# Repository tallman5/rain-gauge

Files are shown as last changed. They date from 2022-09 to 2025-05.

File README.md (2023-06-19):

## Links
||Desc|Link|
|---|---|---|
|**Documentation**|Published docs and Discuss|[https://www.mcgurkin.net/posts/rain-gauge](https://www.mcgurkin.net/posts/rain-gauge)|
|**YouTube**|Short video of tipper working|[https://youtu.be/XX34wHzLibE](https://youtu.be/XX34wHzLibE)|
|**Rain History**|Sensor output charts|[https://www.mcgurkin.net/apps/rain](https://www.mcgurkin.net/apps/rain)|
|**BOM**|List of parts required for full build|[https://github.com/tallman5/rain-gauge/blob/main/rain-gauge-bom.md](https://github.com/tallman5/rain-gauge/blob/main/rain-gauge-bom.md)|
|**Fusion Model**|The STLs in GitHub are the "production" version. The Fusion model may have changes which have not been tested.|[https://a360.co/3bst4iC](https://a360.co/3bst4iC)|

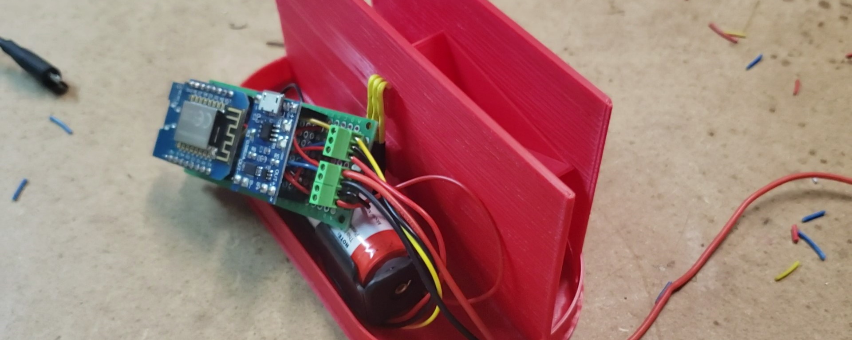
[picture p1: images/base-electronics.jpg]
Rain Gauge Electronics


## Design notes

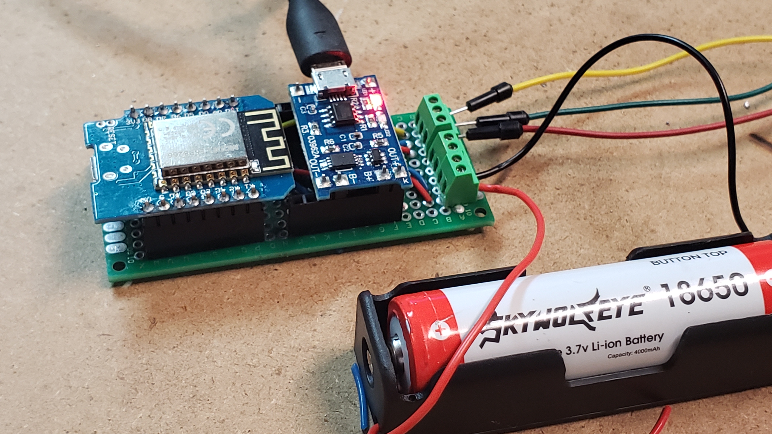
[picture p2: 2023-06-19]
images/rain-gauge-electronics.jpg

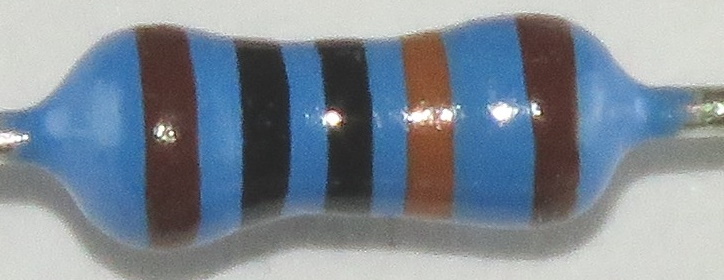
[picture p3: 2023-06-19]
images/100k-resistor.jpg

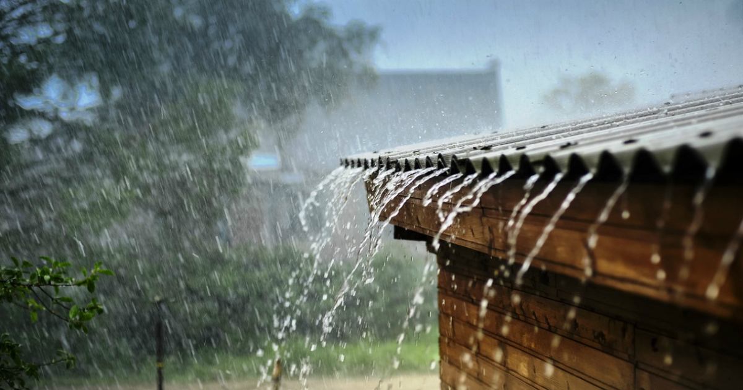
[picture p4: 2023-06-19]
images/rain-roof.jpg

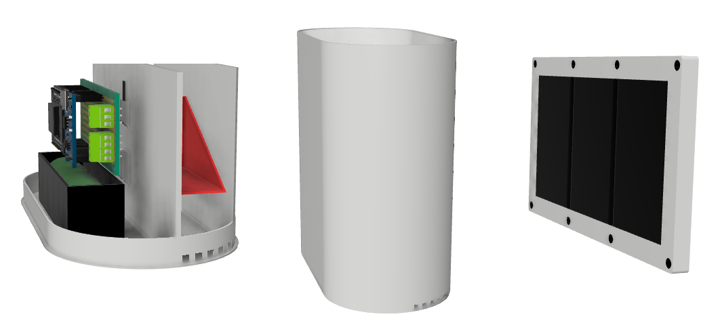
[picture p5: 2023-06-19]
images/rain-gauge.png

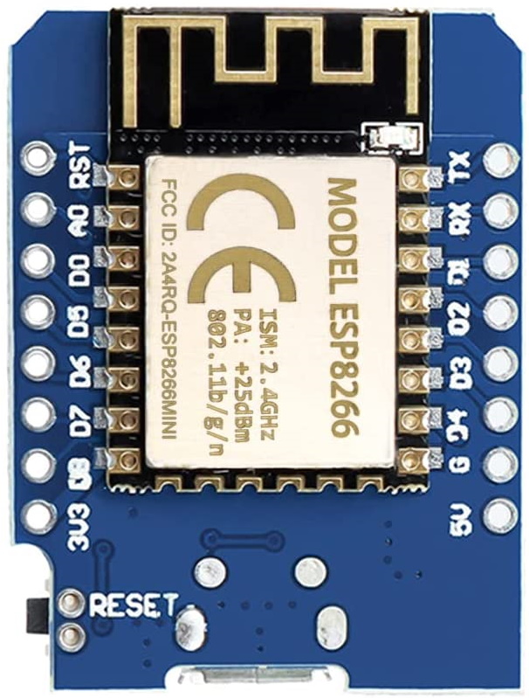
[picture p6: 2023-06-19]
images/ESP8266-top.jpg

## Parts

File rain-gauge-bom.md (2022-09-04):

# Rain Gauge BOM
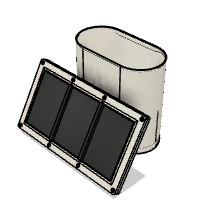
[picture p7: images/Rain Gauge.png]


As an Amazon Associate I earn from qualifying purchases. The products in the links below will not cost you any more than normally. However, using these links helps support this and other projects. Thank you!

|Image|Number|Quantity|Description|
|-|-|-|-|
||18650 Battery|1|https://amzn.to/3APuPyO|
||18650 Holder|1|https://amzn.to/3TGcAo7|
||2.54 Header 1 Pin Male|2|https://amzn.to/3KK6nDy|
||2.54 Header 2 Pin Male|2|https://amzn.to/3KK6nDy|
||2.54 Header 8 Pin Female|4|https://amzn.to/3CS7b7p|
||2.54 Header 8 Pin Male|2|https://amzn.to/3CS7b7p|
||5v Solar Panel|3|https://amzn.to/3wUnVHu|
||Hall Sensor AH3364Q|1|https://amzn.to/3qakI2M|
||Schottky Diode 1N5817|3|https://amzn.to/3CWOjnV|
||ESP8266 12F|1|https://amzn.to/3CS7b7p|
||KF128-2.54-2P|2|https://amzn.to/3KK6nDy|
||KF128-2.54-3P|1|https://amzn.to/3KK6nDy|
||M3x5x4 Threaded Insert|8|https://amzn.to/3AGMAjQ|
||M3x6 SHCS|8|https://amzn.to/3QjYiGJ|
||M6x3 Magnet|1|https://amzn.to/3RhCIUT|
||panel-holder-bottom|1|3D Printed Part|
||panel-holder-top|1|3D Printed Part|
||Prototype Board 24x10|1|https://amzn.to/3KK6nDy|
||rain-gauge-base|1|3D Printed Part|
||rain-gauge-cup|1|3D Printed Part|
||rain-gauge-top|1|3D Printed Part|
||Resistor - 100K|2|https://amzn.to/3AP3Za0|
||TP4056|1|https://amzn.to/3e9tIST|

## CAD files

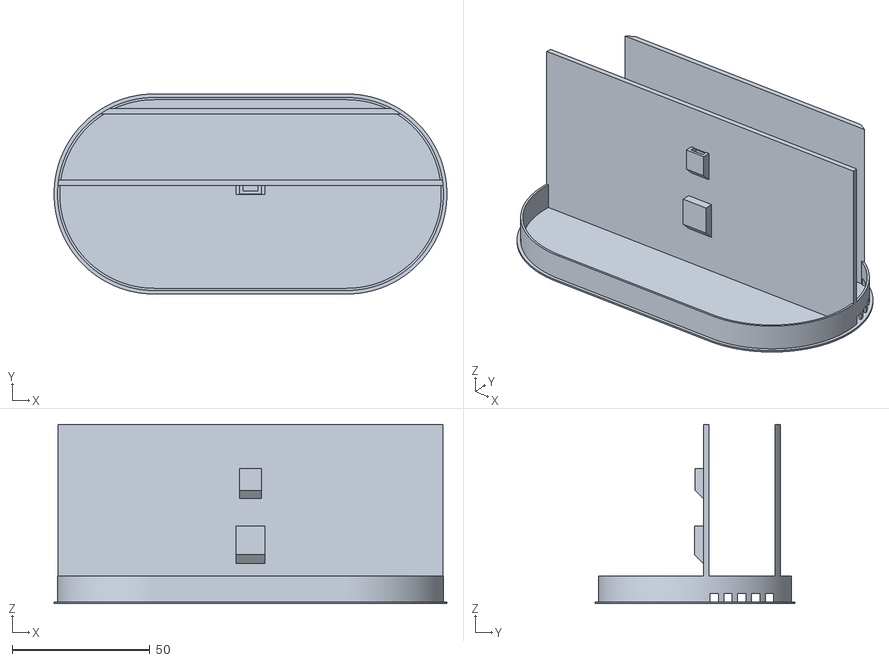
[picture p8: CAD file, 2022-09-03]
stl/rain-gauge-base.stl
142.6 x 72.6 x 65.0

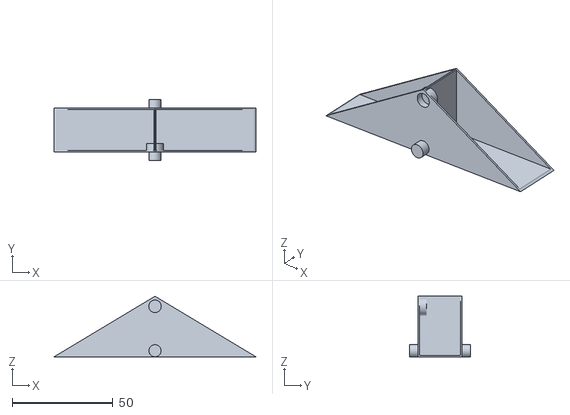
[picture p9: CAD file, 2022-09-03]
stl/rain-gauge-cup.stl
100.0 x 30.0 x 30.0

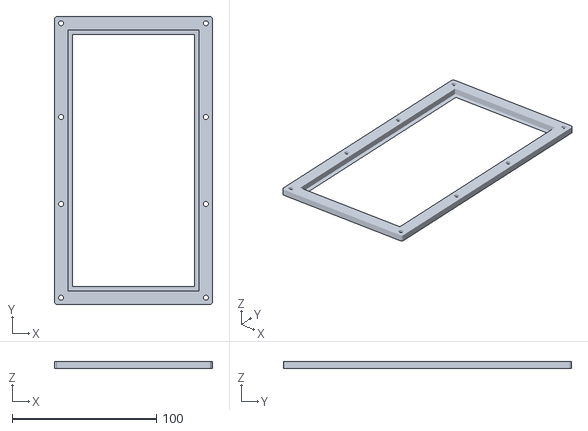
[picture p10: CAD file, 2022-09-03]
stl/panel-holder-top.stl
109.8 x 199.8 x 4.60

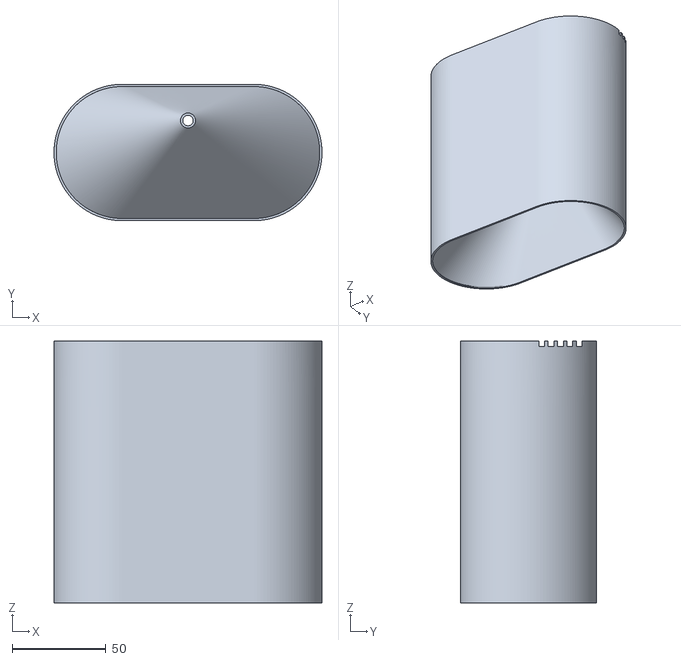
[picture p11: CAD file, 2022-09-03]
stl/rain-gauge-top.stl
142.6 x 72.6 x 139.4

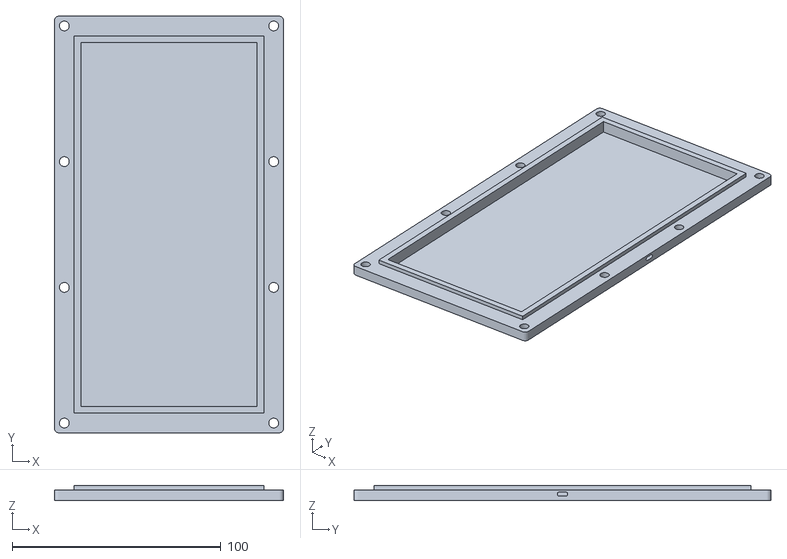
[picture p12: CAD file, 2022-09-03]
stl/panel-holder-bottom.stl
109.8 x 199.8 x 7.00

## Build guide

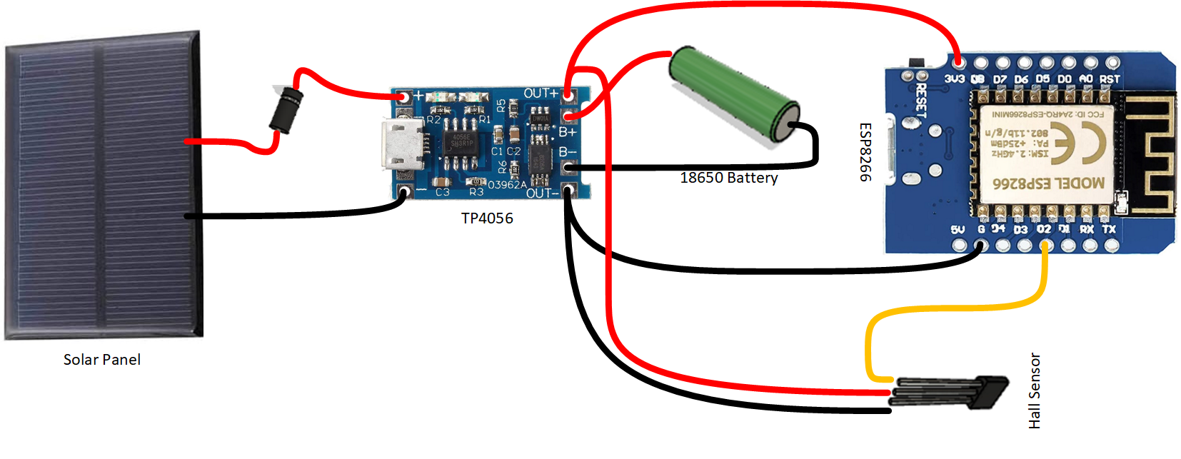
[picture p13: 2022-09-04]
images/rain-gauge-wiring.png

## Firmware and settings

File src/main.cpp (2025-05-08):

#include <ArduinoJson.h>
#include <ESP8266HTTPClient.h>
#include <ESP8266mDNS.h>
#include <ESP8266WiFi.h>
#include <list>
#include <time.h>
#include "secrets.h"

#define INTERRUPT_PIN D2
#define VOLTAGE_PIN A0

const char *hostName = HOST_NAME;
const char *ssid = STASSID;
const char *wifiPassword = STAPSK;
const char *baseApiUrl = BASE_API_URL;
const char *iotName = IOT_NAME;
const char *iotPassword = IOT_PASSWORD;

float voltCalibration = 0.382;
long lastPostTime = 0;
String accessToken;
std::list<long> epochs;
String bulkUploadEndpoint = "/kpis/" + String(hostName);
int counter = 0;

void turnOffWifi()
{
  Serial.print("Disconnecting WiFi..");
  WiFi.mode(WIFI_OFF);
  while (WiFi.status() == WL_CONNECTED)
  {
    Serial.print(".");
    delay(1000);
  }
  Serial.println("done");
}

void turnOnWifi()
{
  Serial.print("Connecting to WiFi.");
  WiFi.hostname(hostName);
  WiFi.mode(WIFI_STA);
  WiFi.begin(ssid, wifiPassword);
  while (WiFi.status() != WL_CONNECTED)
  {
    delay(1000);
    Serial.print(".");
  }
  Serial.println("done");
  Serial.println("IP address: " + WiFi.localIP().toString());
  Serial.println("MAC address: " + WiFi.macAddress());
}

IRAM_ATTR void hallChanged()
{
  const int currentRead = digitalRead(INTERRUPT_PIN);
  if (currentRead == 0)
  {
    long now = time(nullptr);
    epochs.push_back(now);
    digitalWrite(LED_BUILTIN, LOW);
    Serial.println("Hall effect sensor triggered.");
  }
  else
  {
    digitalWrite(LED_BUILTIN, HIGH);
  }
}

int postJsonWithAuth(const String &endpoint, const String &jsonBody)
{
  if (WiFi.status() != WL_CONNECTED || accessToken.isEmpty())
    return -1;

  std::unique_ptr<BearSSL::WiFiClientSecure> client(new BearSSL::WiFiClientSecure);
  client->setInsecure();

  HTTPClient https;
  if (!https.begin(*client, String(baseApiUrl) + endpoint))
  {
    Serial.println("Unable to connect to server for " + endpoint);
    return -1;
  }

  https.addHeader("Content-Type", "application/json");
  https.addHeader("Authorization", "Bearer " + accessToken);

  int httpCode = https.POST(jsonBody);
  Serial.printf("POST to %s response code: %d\n", endpoint.c_str(), httpCode);

  if (httpCode <= 0)
  {
    Serial.printf("Failed to POST to %s, error: %s\n", endpoint.c_str(), https.errorToString(httpCode).c_str());
    String errorPayload = https.getString();
    Serial.println("Error Response: " + errorPayload);
  }

  https.end();
  return httpCode;
}

String createKpiJson(const String &keyName, float keyValue, long epoch)
{
  String json = "{";
  json += "\"keyName\":\"" + keyName + "\",";
  json += "\"keyValue\":" + String(keyValue, 2) + ",";
  json += "\"epoch\":" + String(epoch);
  json += "}";
  return json;
}

void postKpis(bool includeTips)
{
  int sensorValue = analogRead(VOLTAGE_PIN);
  float voltage = ((sensorValue * (3.3 / 1024.0)) * 2) + voltCalibration;
  int battPercent = (voltage - 2.5) * 100 / (4.2 - 2.5);
  long now = time(nullptr);

  String json = "{ \"kpis\": [";
  bool first = true;

  if (includeTips)
  {
    for (auto it = epochs.begin(); it != epochs.end(); ++it)
    {
      if (!first)
        json += ",";
      json += createKpiJson("tip", 1, *it);
      first = false;
    }
  }

  if (!first)
    json += ",";
  json += createKpiJson("volt", voltage, now);
  json += "," + createKpiJson("volt-pin", sensorValue, now);
  json += "," + createKpiJson("batt", battPercent, now);

  json += "] }";

  int httpCode = postJsonWithAuth(bulkUploadEndpoint, json);
  if (httpCode >= 200 && httpCode < 300 && includeTips)
  {
    epochs.clear();
  }
}

void signIn(const String &username, const String &password, bool rememberMe)
{
  if (WiFi.status() != WL_CONNECTED)
  {
    Serial.println("WiFi not connected. Cannot sign in.");
    return;
  }

  std::unique_ptr<BearSSL::WiFiClientSecure> client(new BearSSL::WiFiClientSecure);
  client->setInsecure();

  HTTPClient https;
  if (!https.begin(*client, String(baseApiUrl) + "/iam/signin"))
  {
    Serial.println("Unable to connect to server.");
    return;
  }
  https.addHeader("Content-Type", "application/json");

  String body = "{\"username\":\"" + username + "\",\"password\":\"" + password + "\",\"rememberMe\":" + (rememberMe ? "true" : "false") + "}";
  int httpCode = https.POST(body);

  if (httpCode > 0)
  {
    String payload = https.getString();

    JsonDocument doc;
    DeserializationError error = deserializeJson(doc, payload);

    if (error)
    {
      Serial.print("JSON parsing failed: ");
      Serial.println(error.f_str());
    }
    else if (doc["data"]["accessToken"].is<String>())
    {
      accessToken = doc["data"]["accessToken"].as<String>();
      Serial.println("Signing in succeeded.");
    }
    else
    {
      Serial.println("No accessToken in response.");
    }
  }
  else
  {
    Serial.printf("Sign-in failed, error: %s\n", https.errorToString(httpCode).c_str());
  }

  https.end();
}

void updateClock()
{
  configTime(0, 0, "pool.ntp.org", "time.nist.gov");

  Serial.print("Waiting for NTP time sync.");
  time_t now = time(nullptr);
  int retries = 0;

  while (now < 8 * 3600 * 2 && retries < 100)
  {
    delay(1000);
    Serial.print(".");
    now = time(nullptr);
    retries++;
  }

  if (now >= 8 * 3600 * 2)
  {
    Serial.println("done.");
    Serial.println(ctime(&now));
  }
  else
  {
    Serial.println();
    Serial.println("Failed to sync time.");
  }
}

void setup()
{
  delay(5000);
  Serial.begin(115200);

  turnOnWifi();
  updateClock();
  turnOffWifi();

  pinMode(INTERRUPT_PIN, INPUT_PULLUP);
  attachInterrupt(digitalPinToInterrupt(INTERRUPT_PIN), hallChanged, CHANGE);
  pinMode(LED_BUILTIN, OUTPUT);
  digitalWrite(LED_BUILTIN, HIGH);
}

void loop()
{
  if (!epochs.empty() || counter == 0)
  {
    turnOnWifi();
    signIn(iotName, iotPassword, false);
    postKpis(true);
    turnOffWifi();
    counter = 0;
  }

  delay(60 * 1000);

  counter++;
  if (counter > 120)
  {
    counter = 0;
  }
}
